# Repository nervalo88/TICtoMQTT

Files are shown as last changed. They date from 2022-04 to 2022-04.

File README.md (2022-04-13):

# TICtoMQTT
*interface from french electricity meters to MQTT.*

ENEDIS (former Electricité De France) electricity meter generates some informational signal as Serial ASCII frames e.g:
```
ADCO xxxxxxxxxxxx 2
OPTARIF BASE 0
ISOUSC 30 9
BASE 025298937 8
PTEC TH.. $
IINST 011 Y
IMAX 042 E
PAPP 02550 -
MOTDETAT 000000 B
```
full documentation (french) : https://www.enedis.fr/media/2027/download

## Hardware
Check [./Hardware](./Hardware) for kicad project

## Sofware
### TICtoMQTT
Main software to pass BASE and PPAP values over MQTT
### HWtest
[HWtest](./HWtest) is a quick sketch to get raw frame content

## CAD
Check [./CAD](./CAD) for a 3D printable enclosure for this project, held on DIN rail for electric panels

## References 
[MQTT on ESP](https://randomnerdtutorials.com/esp32-mqtt-publish-subscribe-arduino-ide/)

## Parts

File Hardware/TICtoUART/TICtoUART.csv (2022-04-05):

Source: | E:\OneDrive\20.BRICOLE-ELECTRONIQUE\TIC\TICtoUART\TICtoUART.kicad_sch
Date: | 25/03/2022 22:04:29
Tool: | Eeschema (6.0.4)
Generator: | C:\Program Files\KiCad\6.0\bin\scripting\plugins/bom_csv_grouped_by_value_with_fp.py
Component Count: | 8
Ref | Qnty | Value | Cmp name | Footprint | Description | Vendor
D1, | 1 | 1N4001 | 1N4001 | Diode_THT:D_DO-41_SOD81_P10.16mm_Horizontal | 50V 1A General Purpose Rectifier Diode, DO-41
J1, | 1 | Conn_01x02_Male | Conn_01x02_Male | Connector_PinHeader_2.54mm:PinHeader_1x01_P2.54mm_Vertical | Generic connector, single row, 01x02, script generated (kicad-library-utils/schlib/autogen/connector/)
J2, | 1 | Conn_01x03_Male | Conn_01x03_Male | Connector_PinHeader_2.54mm:PinHeader_1x01_P2.54mm_Vertical | Generic connector, single row, 01x03, script generated (kicad-library-utils/schlib/autogen/connector/)
R1, R2, | 2 | R | R | Resistor_THT:R_Axial_DIN0207_L6.3mm_D2.5mm_P5.08mm_Vertical | Resistor
RV1, | 1 | R_Potentiometer | R_Potentiometer | Potentiometer_THT:Potentiometer_ACP_CA14V-15_Vertical_Hole | Potentiometer
U1, | 1 | SFH617A-2X009T | SFH617A-2X009T | Package_DIP:SMDIP-4_W7.62mm | Optocoupler, Phototransistor Output, 5300 VRMS, VCEO 70V, CTR% 63-125, -55 to +110 degree Celcius, UL, BSI, FIMKO, SMD PDIP-4
U2, | 1 | LM358 | LM358 | Package_DIP:DIP-8_W7.62mm_Socket_LongPads | Low-Power, Dual Operational Amplifiers, DIP-8/SOIC-8/TO-99-8

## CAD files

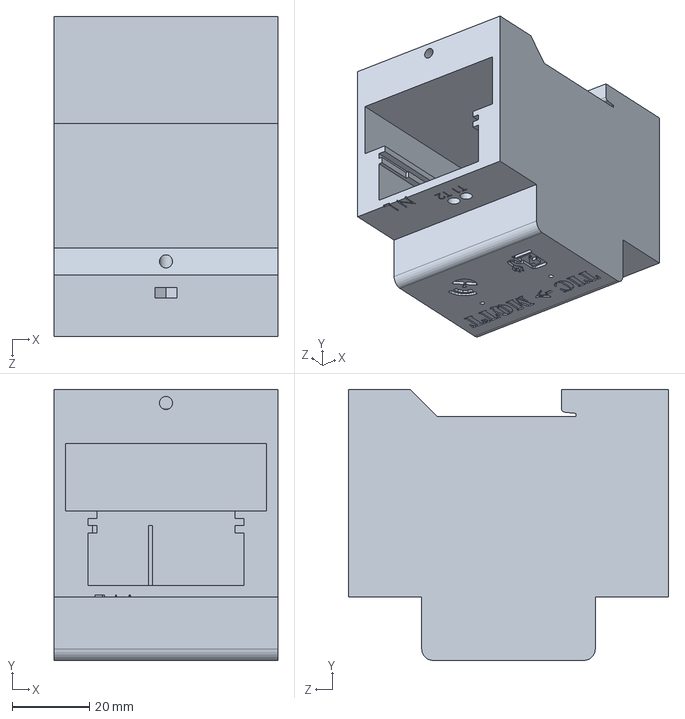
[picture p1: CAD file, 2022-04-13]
CAD/Case.SLDPRT
58.0 x 70.3 x 83.0 mm

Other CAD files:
CAD/Case.STL

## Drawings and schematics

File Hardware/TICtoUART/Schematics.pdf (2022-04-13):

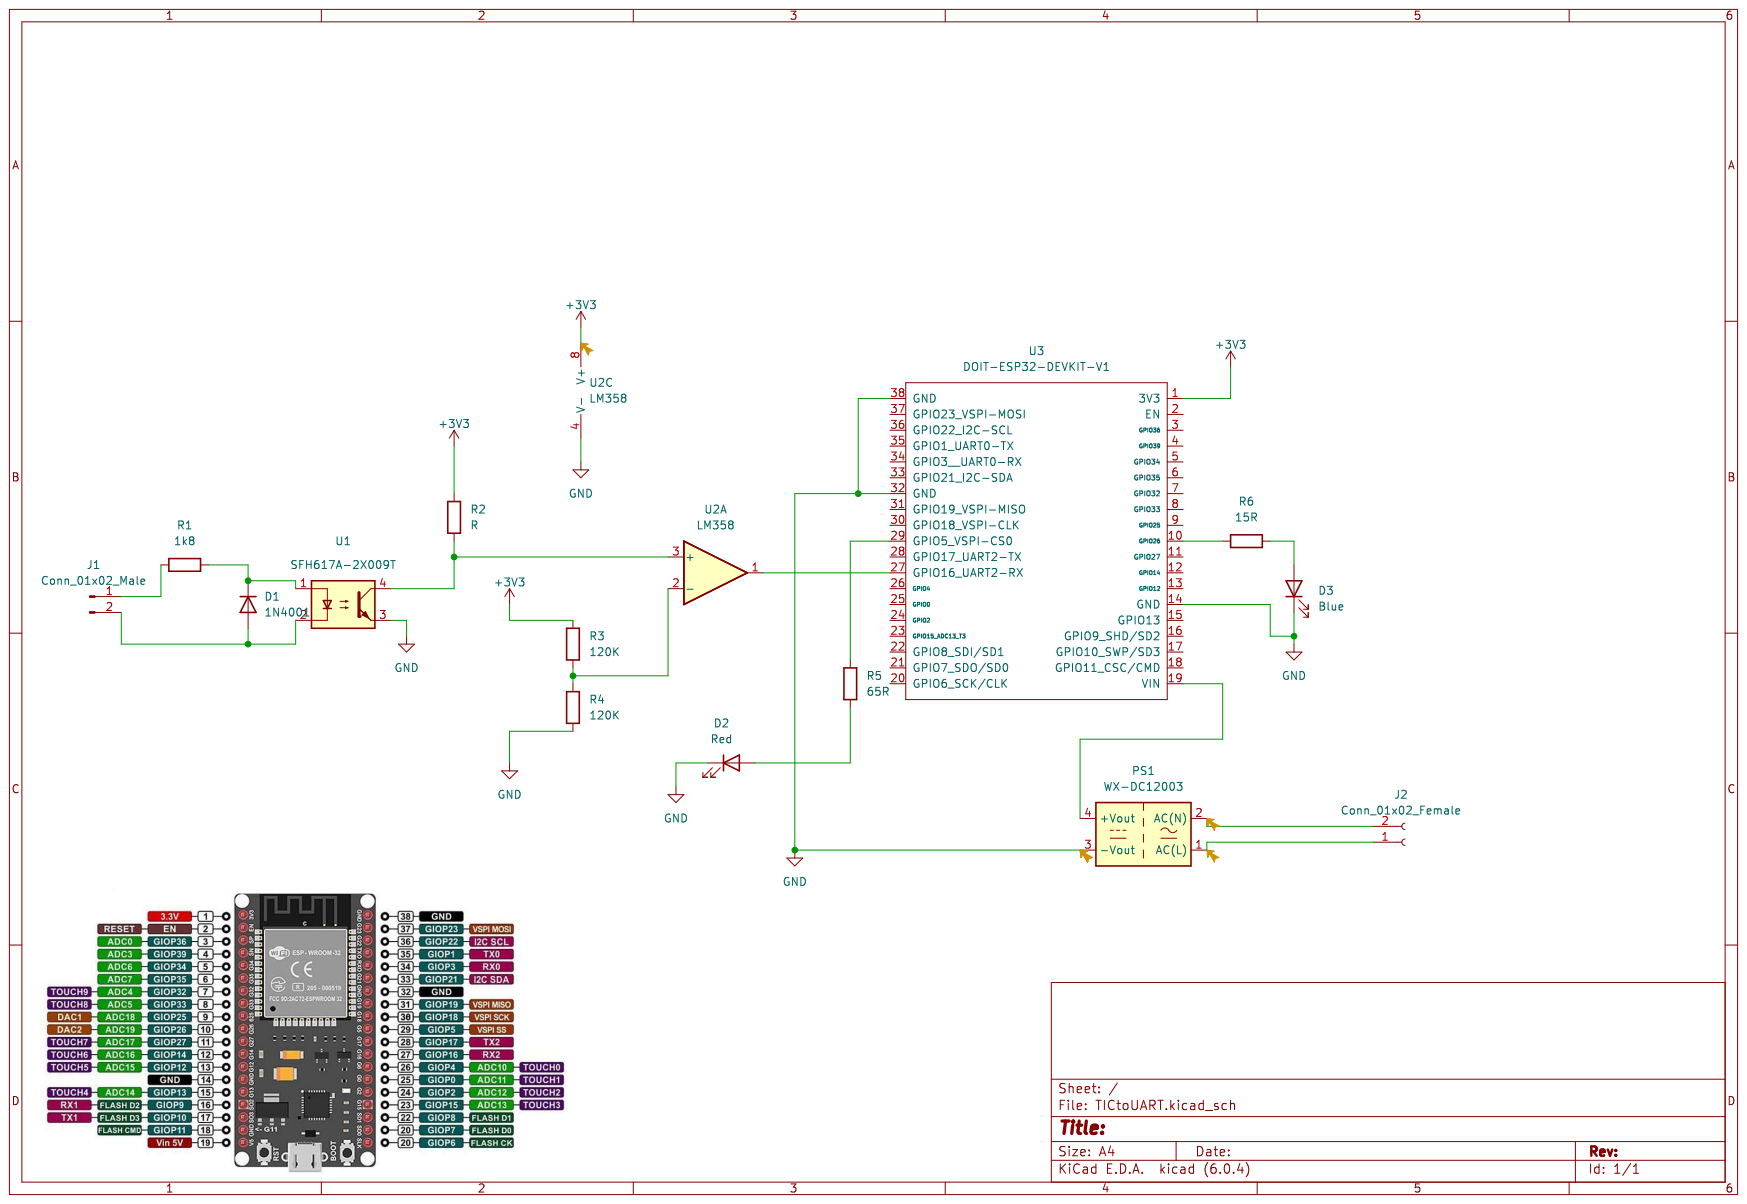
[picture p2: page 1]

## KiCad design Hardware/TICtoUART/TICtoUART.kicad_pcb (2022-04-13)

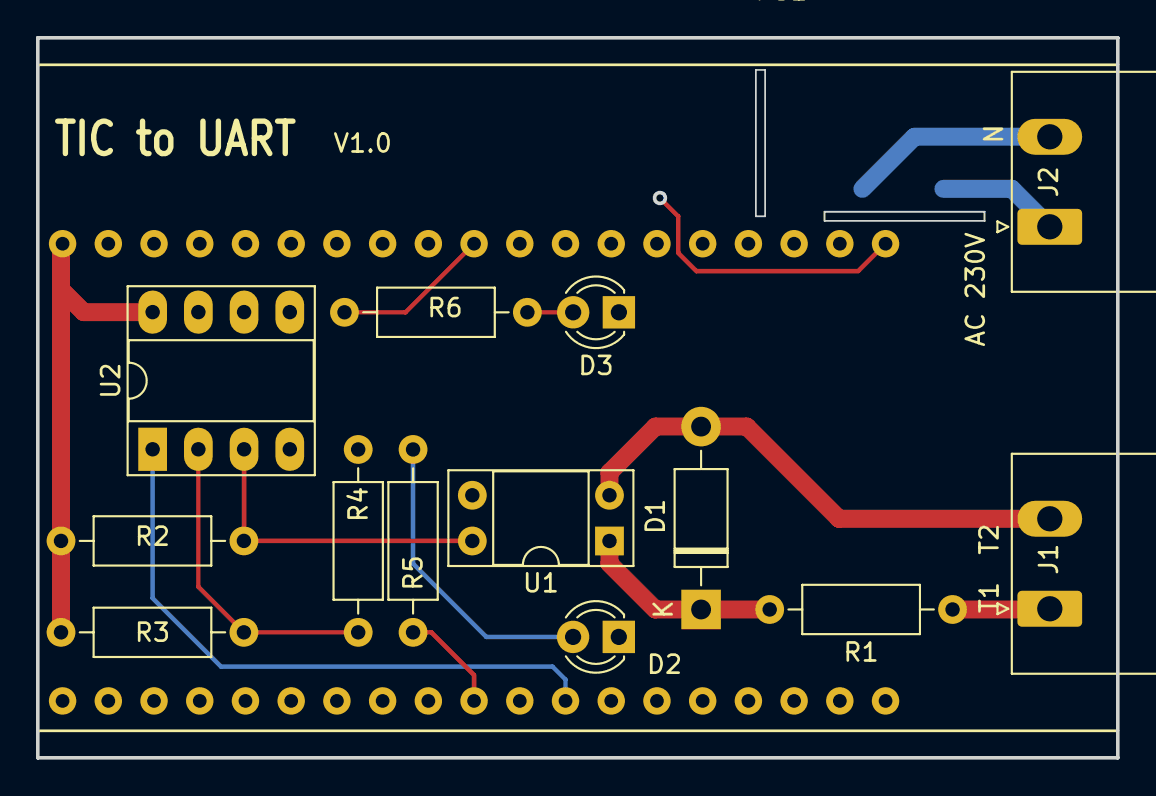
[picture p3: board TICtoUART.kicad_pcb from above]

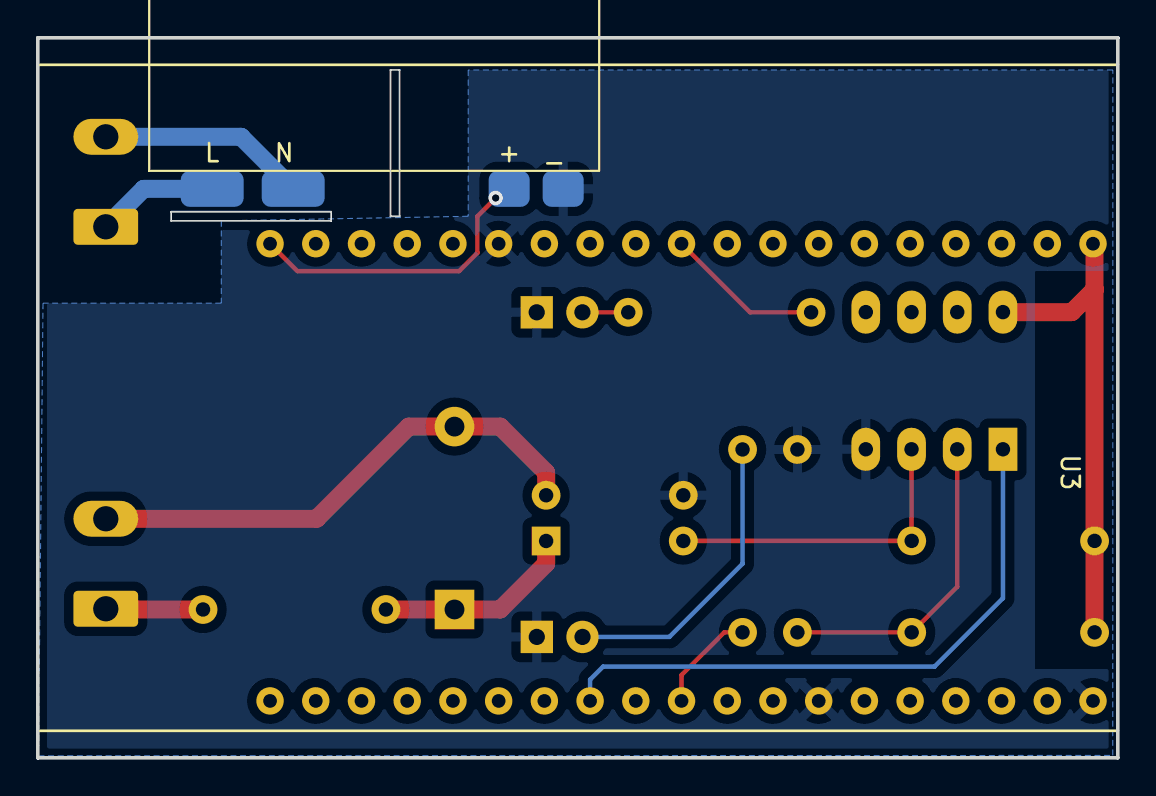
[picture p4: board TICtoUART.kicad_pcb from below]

Board: 2 copper layers, 60.0 x 40.0 mm, 15 parts (2 on the bottom side), 15 nets.

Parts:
D1: 1N4001; D_DO-41_SOD81_P10.16mm_Horizontal
D2: Red; LED_D3.0mm
D3: Blue; LED_D3.0mm
J1: Conn_01x02_Male; PhoenixContact_MSTBA_2,5_2-G_1x02_P5.00mm_Horizontal
J2: Conn_01x02_Female; PhoenixContact_MSTBA_2,5_2-G_1x02_P5.00mm_Horizontal
PS1: WX-DC12003
R1: 1k8; R_Axial_DIN0207_L6.3mm_D2.5mm_P10.16mm_Horizontal
R2: R; R_Axial_DIN0207_L6.3mm_D2.5mm_P10.16mm_Horizontal
R3, R4: 120K; R_Axial_DIN0207_L6.3mm_D2.5mm_P10.16mm_Horizontal
R5: 65R; R_Axial_DIN0207_L6.3mm_D2.5mm_P10.16mm_Horizontal
R6: 15R; R_Axial_DIN0207_L6.3mm_D2.5mm_P10.16mm_Horizontal
U1: SFH617A-2X009T; DIP-4_W7.62mm_Socket
U2: LM358; DIP-8_W7.62mm_Socket_LongPads
U3: DOIT-ESP32-DEVKIT-V1; ESP_WROOM_32-DOIT-DEVKIT

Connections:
+3V3: R2.1, R3.1, U2.8 (V+), U3.1 (3V3)
GND: D2.1 (K), D3.1 (K), PS1.3 (-Vout), R4.2, U1.3, U2.4 (V-), U3.14 (GND), U3.32 (GND), U3.38 (GND)
unnamed: D1.1 (K), R1.2, U1.1
unnamed: D1.2 (A), J1.2, U1.2
unnamed: D2.2 (A), R5.2
unnamed: D3.2 (A), R6.2
unnamed: J1.1, R1.1
unnamed: J2.1, PS1.1 (AC(L))
unnamed: J2.2, PS1.2 (AC(N))
unnamed: PS1.4 (+Vout), U3.19 (VIN)
unnamed: R2.2, U1.4, U2.3 (+)
unnamed: R3.2, R4.1, U2.2 (-)
unnamed: U2.1, U3.27 (GPIO16_UART2-RX)
unnamed: R6.1, U3.10 (GPIO26)
unnamed: R5.1, U3.29 (GPIO5_VSPI-CS0)

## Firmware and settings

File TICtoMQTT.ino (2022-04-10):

/*
 Name:		TICtoMQTT.ino
 Created:	03/04/2022 18:20:20
 Author:	renau
*/



#include <WiFi.h>   
#include <DNSServer.h>
#include <WebServer.h>
#include <WiFiManager.h>
#include <strings_en.h>
WiFiManager wifiManager;
#include <PubSubClient.h>

WiFiClient espCLient;
PubSubClient client(espCLient);

#include "Secret.h"

#define STATUSLED_TIC 5
bool ticState;
#define STATUSLED_WIFI 26 

String data;
String ppap;
String base;


char ppapVal[5];
char baseVal[9];

long lastMsg = 0;


void setup() {
	Serial.begin(9600);
	Serial2.begin(1200, SERIAL_7N1);
	wifiManager.autoConnect("TICtoMQTT");

	client.setServer(mqtt_server, 1883);
	//client.setCallback(callback); //NOT NEEDED : no input
	pinMode(STATUSLED_TIC, OUTPUT);
	pinMode(STATUSLED_WIFI, OUTPUT);

	digitalWrite(STATUSLED_WIFI, false);
	if(WiFi.status() == WL_CONNECTED) digitalWrite(STATUSLED_WIFI, true);



}

long i = 0;

// the loop function runs over and over again until power down or reset
void loop() {
	if (!client.connected()) {
		digitalWrite(STATUSLED_WIFI, false);
		reconnect();
	}
	client.loop();

	/*long now = millis();
	if (now - lastMsg > 500) {
		lastMsg = now;
		
		digitalWrite(STATUSLED_WIFI, !ticState);
		
	}*/
		if (Serial2.available()) {

			data = Serial2.readStringUntil('\n');
			if (data.startsWith("PAPP")) {
				ppap = data.substring(5, 10);
				strcpy(ppapVal, ppap.c_str());

				client.publish("espTIC/ppap", ppapVal, 1);

				Serial.print("Power: ");
				Serial.println(ppapVal);
			}
			if (data.startsWith("BASE")) {
				base = data.substring(5, 14);
				strcpy(baseVal, base.c_str());
				client.publish("espTIC/base", baseVal, 1);
				Serial.print("base:");
				Serial.println(baseVal);
				digitalWrite(STATUSLED_TIC, ticState);
				ticState = !ticState;
				
			}

		}
	//}
}

void reconnect() {
	// Loop until we're reconnected
	while (!client.connected()) {
		Serial.print("Attempting MQTT connection...");
		// Attempt to connect
		if (client.connect("EspTICClient")) {
			Serial.println("connected");
			digitalWrite(STATUSLED_WIFI, true);
			// Subscribe
		}
		else {
			Serial.print("failed, rc=");
			Serial.print(client.state());
			Serial.println(" try again in 5 seconds");
			// Wait 5 seconds before retrying
			delay(5000);
		}
	}
}

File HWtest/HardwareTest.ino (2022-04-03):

/*
 Name:		TICtoMQTT.ino
 Created:	03/04/2022 18:20:20
 Author:	renau
*/

String data;

void setup() {
	Serial.begin(9600);
	Serial2.begin(1200, SERIAL_7N1);
}

long i = 0;

// the loop function runs over and over again until power down or reset
void loop() {
  
	if (Serial2.available()) {
		Serial.print((char)Serial2.read());
	}
	/*
	i++;
	Serial.printf("Test \"Serial\" - %d\n", i);
	delay(500);
	*/

}

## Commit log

2022-04-03 Ajoutez les fichiers .gitignore et .gitattributes.
2022-04-03 Ajoutez des fichiers projet.
2022-04-03 1st commit : material test, send raw data to Serial
2022-04-05 Added Hardware kicad porject
    [TICtoUART-B_Cu.gbl, TICtoUART-B_Mask.gbs, TICtoUART-B_Paste.gbp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]
2022-04-10 added MQTT + status LED
    [TICtoUART.kicad_pcb, TICtoUART.kicad_sch]
2022-04-13 Fully reworked PCB to host an ESP32 devkit Added CAD for enclosuer
    [Case.SLDPRT, Case.STL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]
